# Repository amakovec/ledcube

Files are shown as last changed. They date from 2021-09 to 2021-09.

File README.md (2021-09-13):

# blinky++ - An LED cube with some neat features

## Status

**This project has not yet been tested.  Boards are on their way and bring-up FW writing is in-progress.**

## Features

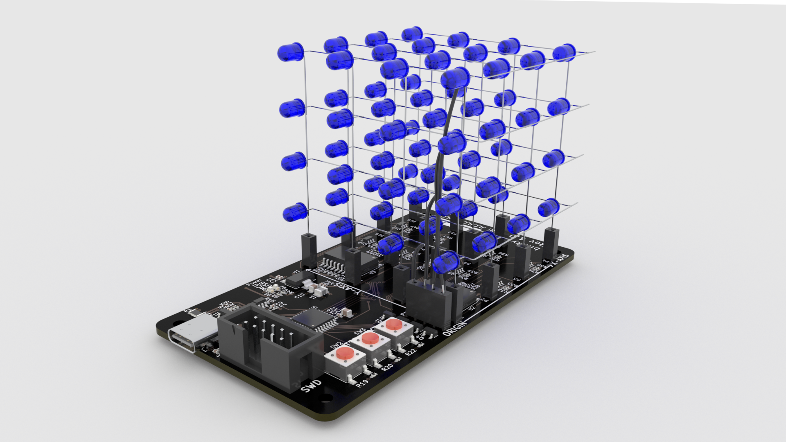
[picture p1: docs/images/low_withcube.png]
blinky++ full rendering


* Multiplex layers at >=120 Hz to create a persistence-of-vision effect
* USB-C for power and communications (except flashing)
    * Set current limit based on CC1 and CC2 voltage (not USB PD)
* Headers to allow for removal of the LED cube
* 30mA per LED
* Buttons to change displayed LED patterns
* Adjustable brightness
    * Limit brightness based on USB current limit determined above

## Hardware

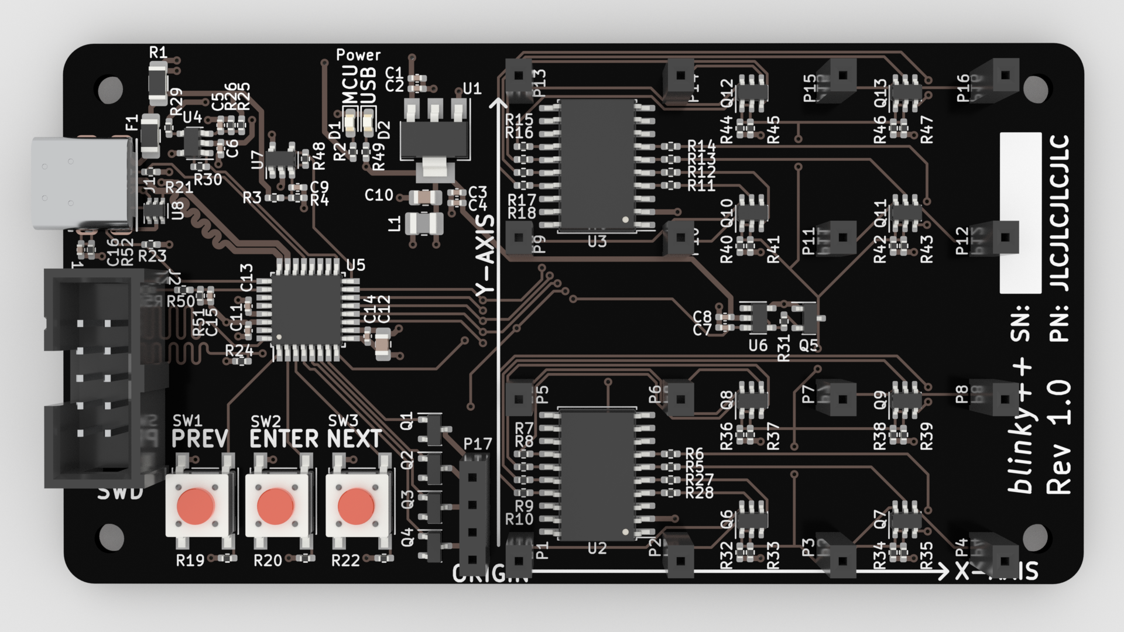
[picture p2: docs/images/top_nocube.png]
blinky++ board-only rendering


* 2-layer board
* Less than 100x100mm (most budget PCB fabs have a significant price jump for dimensions larger than this)
* SAMD21-based

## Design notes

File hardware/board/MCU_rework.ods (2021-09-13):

Pin Number | Pin Name | Net Name | Peripheral Mapping | Remapped from v1.0 Schematic? | Previous Pin Number
1 | PA00 | BUTTON_1 | GPIO | No | --
2 | PA01 | BUTTON_2 | GPIO | No | --
3 | PA02 | BRIGHTNESS_DAC | DAC VOUT | Yes | 8
4 | PA03 | U5V_VSENSE | AIN[1] | Yes | 16
5 | PA04 | U5V_CSENSE | AIN[4] | Yes | 17
6 | PA05 | USB_CC1 | AIN[5] | Yes | 21
7 | PA06 | USB_CC2 | AIN[6] | Yes | 25
8 | PA07 | BUTTON_3 | GPIO | Yes | 3
9 | VDDANA | -- | -- | -- | --
10 | GNDIO | -- | -- | -- | --
11 | PA08 | SHIFT_SER_IN | SERCOM2/PAD[0] (DO) | No | --
12 | PA09 | SHIFT_SRCK | SERCOM2/PAD[1] (SCK) | No | --
13 | PA10 | SHIFT_SRCLR | GPIO | No | --
14 | PA11 | SHIFT_RCLK | GPIO | No | --
15 | PA14 | SHIFT_G | GPIO | No | --
16 | PA15 | LED_N_3 | GPIO | Yes | 4
17 | PA16 | LED_N_2 | GPIO | Yes | 5
18 | PA17 | LED_N_1 | GPIO | Yes | 6
19 | PA18 | LED_N_0 | GPIO | Yes | 7
20 | PA19 | -- | -- | -- | --
21 | PA22 | -- | -- | -- | --
22 | PA23 | -- | -- | -- | --
23 | PA24 | USB_N | USB/DM | No | --
24 | PA25 | USB_P | USB/DP | No | --
25 | PA27 | -- | -- | -- | --
26 | RESET_N | -- | -- | -- | --
27 | PA28 | -- | -- | -- | --
28 | GNDIO | -- | -- | -- | --
29 | VDDCORE | -- | -- | -- | --
30 | VDDIN | -- | -- | -- | --
31 | PA30 | SWCLK | Available | No | --
32 | PA31 | SWDIO | Available | No | --

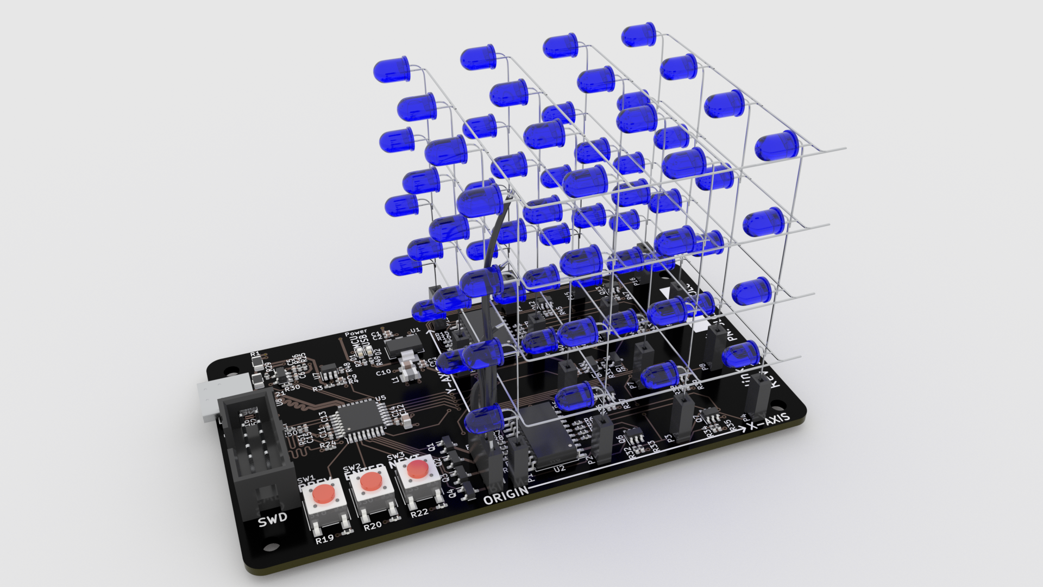
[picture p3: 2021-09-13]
docs/images/high_withcube.png

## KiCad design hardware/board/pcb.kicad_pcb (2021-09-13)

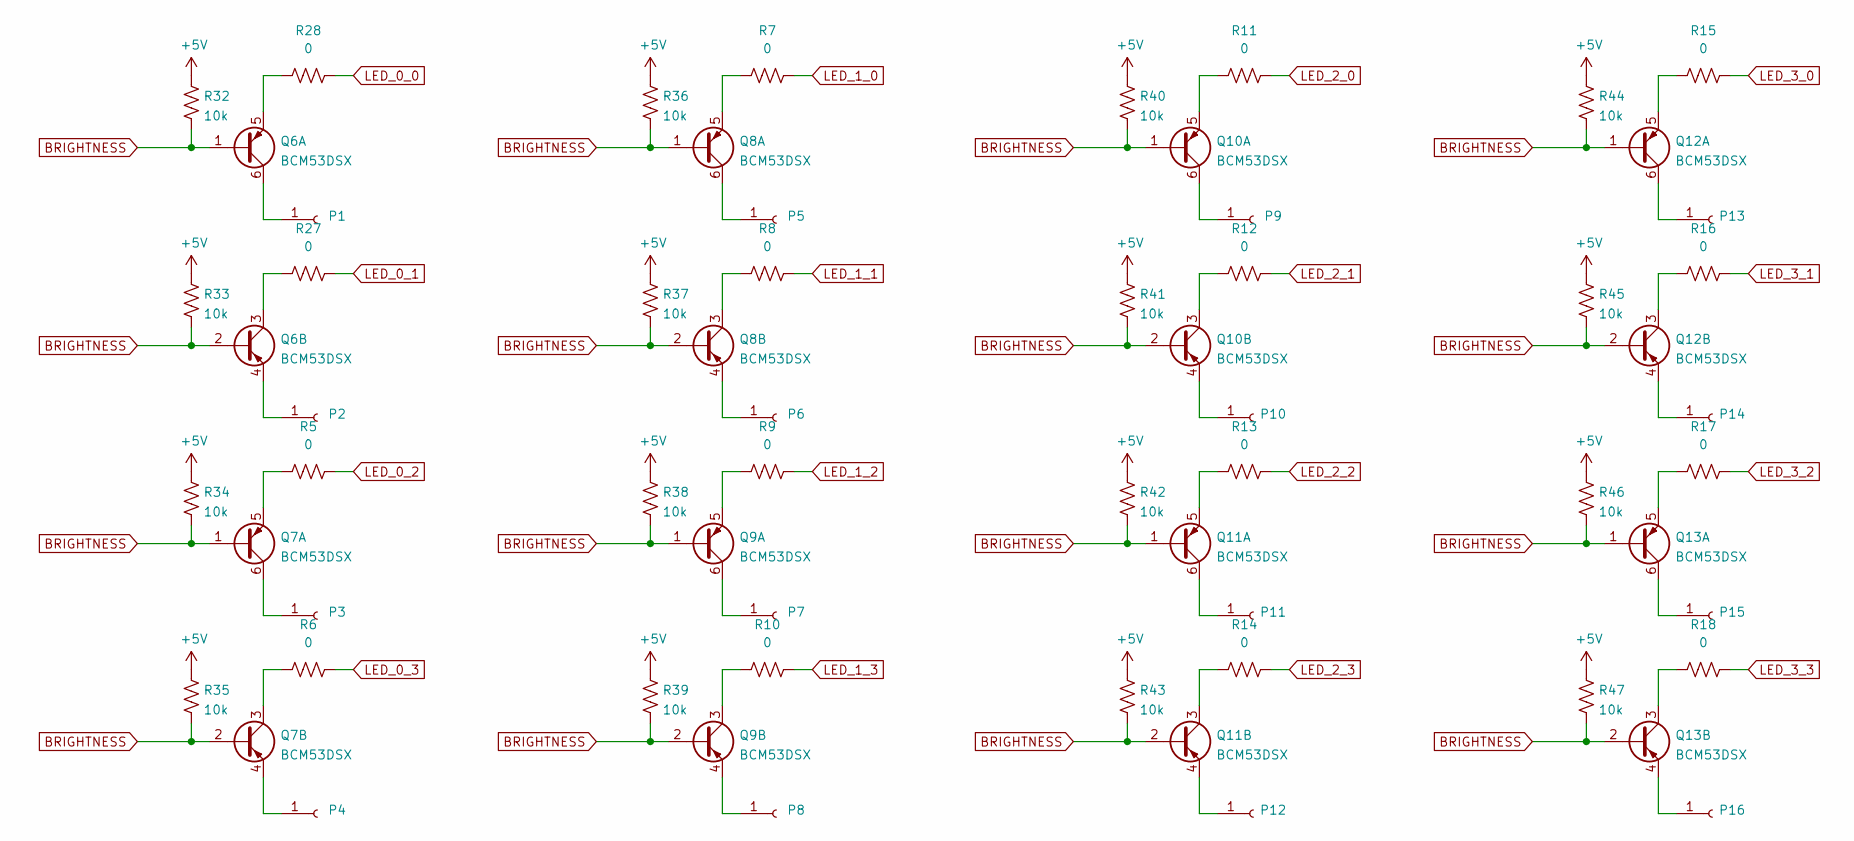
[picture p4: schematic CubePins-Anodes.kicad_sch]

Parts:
P1, P2, P3, P4, P5, P6, P7, P8, P9, P10, P11, P12, P13, P14, P15, P16: SSW-101-01-T-S
Q6, Q7, Q8, Q9, Q10, Q11, Q12, Q13: BCM53DSX; SC-74-6_1.5x2.9mm_P0.95mm
R5, R6, R7, R8, R9, R10, R11, R12, R13, R14, R15, R16, R17, R18, R27, R28: RC0402JR-070RP; R_0402_1005Metric_Pad0.72x0.64mm_HandSolder
R32, R33, R34, R35, R36, R37, R38, R39, R40, R41, R42, R43, R44, R45, R46, R47: RC0402FR-0710KL; R_0402_1005Metric_Pad0.72x0.64mm_HandSolder; Tolerance 1%

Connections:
+5V: R32.1, R33.1, R34.1, R35.1, R36.1, R37.1, R38.1, R39.1, R40.1, R41.1, R42.1, R43.1, R44.1, R45.1, R46.1, R47.1; also elsewhere on the board
BRIGHTNESS: Q6.1 (B2), Q6.2 (B2), Q7.1 (B2), Q7.2 (B2), Q8.1 (B2), Q8.2 (B2), Q9.1 (B2), Q9.2 (B2), Q10.1 (B2), Q10.2 (B2), Q11.1 (B2), Q11.2 (B2), Q12.1 (B2), Q12.2 (B2), Q13.1 (B2), Q13.2 (B2), R32.2, R33.2, R34.2, R35.2, R36.2, R37.2, R38.2, R39.2, R40.2, R41.2, R42.2, R43.2, R44.2, R45.2, R46.2, R47.2; also elsewhere on the board
LED_0_0: R28.1; also elsewhere on the board
LED_0_1: R27.1; also elsewhere on the board
LED_0_2: R5.1; also elsewhere on the board
LED_0_3: R6.1; also elsewhere on the board
LED_1_0: R7.1; also elsewhere on the board
LED_1_1: R8.1; also elsewhere on the board
LED_1_2: R9.1; also elsewhere on the board
LED_1_3: R10.1; also elsewhere on the board
LED_2_0: R11.1; also elsewhere on the board
LED_2_1: R12.1; also elsewhere on the board
LED_2_2: R13.1; also elsewhere on the board
LED_2_3: R14.1; also elsewhere on the board
LED_3_0: R15.1; also elsewhere on the board
LED_3_1: R16.1; also elsewhere on the board
LED_3_2: R17.1; also elsewhere on the board
LED_3_3: R18.1; also elsewhere on the board
unnamed: P1.1, Q6.6 (C2)
unnamed: P2.1, Q6.4 (E2)
unnamed: P3.1, Q7.6 (C2)
unnamed: P4.1, Q7.4 (E2)
unnamed: P5.1, Q8.6 (C2)
unnamed: P6.1, Q8.4 (E2)
unnamed: P7.1, Q9.6 (C2)
unnamed: P8.1, Q9.4 (E2)
unnamed: P9.1, Q10.6 (C2)
unnamed: P10.1, Q10.4 (E2)
unnamed: P11.1, Q11.6 (C2)
unnamed: P12.1, Q11.4 (E2)
unnamed: P13.1, Q12.6 (C2)
unnamed: P14.1, Q12.4 (E2)
unnamed: P15.1, Q13.6 (C2)
unnamed: P16.1, Q13.4 (E2)
unnamed: Q6.3 (C2), R27.2
unnamed: Q6.5 (E2), R28.2
unnamed: Q7.3 (C2), R6.2
unnamed: Q7.5 (E2), R5.2
unnamed: Q8.3 (C2), R8.2
unnamed: Q8.5 (E2), R7.2
unnamed: Q9.3 (C2), R10.2
unnamed: Q9.5 (E2), R9.2
unnamed: Q10.3 (C2), R12.2
unnamed: Q10.5 (E2), R11.2
unnamed: Q11.3 (C2), R14.2
unnamed: Q11.5 (E2), R13.2
unnamed: Q12.3 (C2), R16.2
unnamed: Q12.5 (E2), R15.2
unnamed: Q13.3 (C2), R18.2
unnamed: Q13.5 (E2), R17.2

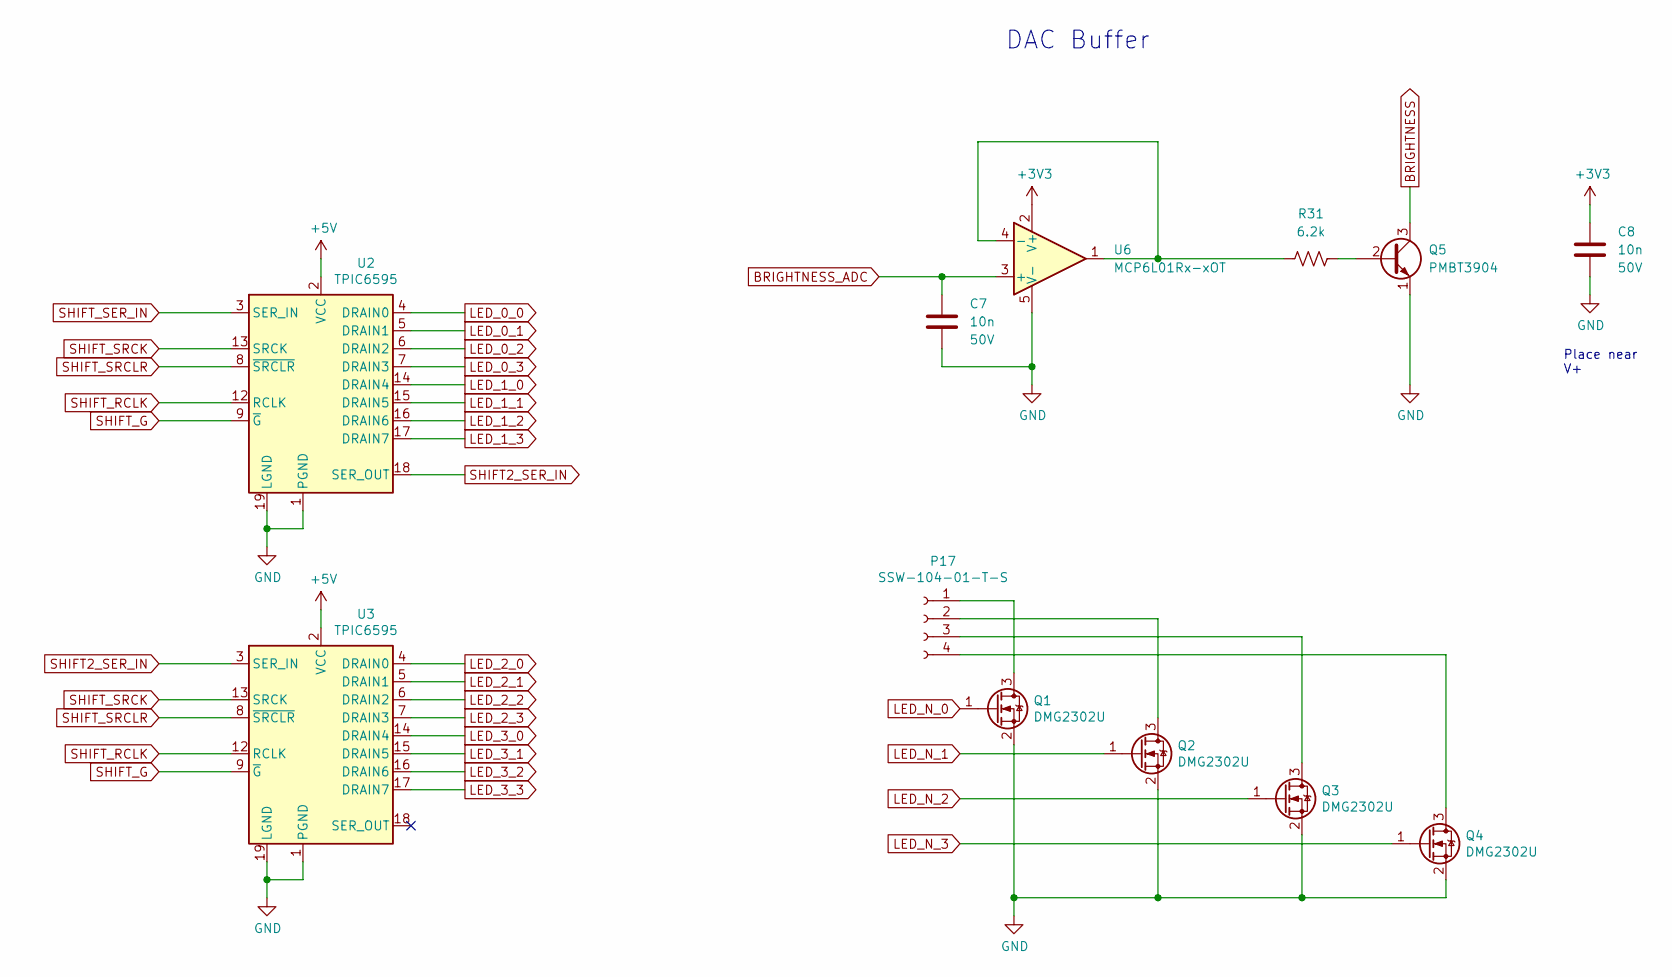
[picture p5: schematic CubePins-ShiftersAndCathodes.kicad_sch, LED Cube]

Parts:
C7, C8: GCM155R71H103KA55D; C_0402_1005Metric_Pad0.74x0.62mm_HandSolder; Voltage 50V; Rating X7R
P17: SSW-104-01-T-S
Q1, Q2, Q3, Q4: DMG2302U; SOT-23
Q5: PMBT3904; SOT-23
R31: RC0402FR-076K2L; R_0402_1005Metric_Pad0.72x0.64mm_HandSolder; Tolerance 1%
U2, U3: TPIC6595; SOIC-20W_7.5x12.8mm_P1.27mm
U6: MCP6L01Rx-xOT; SOT-23-5

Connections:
+3V3: C8.1, U6.2 (V+); also elsewhere on the board
+5V: U2.2 (VCC), U3.2 (VCC); also elsewhere on the board
BRIGHTNESS: Q5.3 (C); also elsewhere on the board
BRIGHTNESS_ADC: C7.1, U6.3 (+); also elsewhere on the board
LED_0_0: U2.4 (DRAIN0); also elsewhere on the board
LED_0_1: U2.5 (DRAIN1); also elsewhere on the board
LED_0_2: U2.6 (DRAIN2); also elsewhere on the board
LED_0_3: U2.7 (DRAIN3); also elsewhere on the board
LED_1_0: U2.14 (DRAIN4); also elsewhere on the board
LED_1_1: U2.15 (DRAIN5); also elsewhere on the board
LED_1_2: U2.16 (DRAIN6); also elsewhere on the board
LED_1_3: U2.17 (DRAIN7); also elsewhere on the board
LED_2_0: U3.4 (DRAIN0); also elsewhere on the board
LED_2_1: U3.5 (DRAIN1); also elsewhere on the board
LED_2_2: U3.6 (DRAIN2); also elsewhere on the board
LED_2_3: U3.7 (DRAIN3); also elsewhere on the board
LED_3_0: U3.14 (DRAIN4); also elsewhere on the board
LED_3_1: U3.15 (DRAIN5); also elsewhere on the board
LED_3_2: U3.16 (DRAIN6); also elsewhere on the board
LED_3_3: U3.17 (DRAIN7); also elsewhere on the board
LED_N_0: Q1.1 (G); also elsewhere on the board
LED_N_1: Q2.1 (G); also elsewhere on the board
LED_N_2: Q3.1 (G); also elsewhere on the board
LED_N_3: Q4.1 (G); also elsewhere on the board
unnamed: P17.1, Q1.3 (D)
unnamed: P17.2, Q2.3 (D)
unnamed: P17.3, Q3.3 (D)
unnamed: P17.4, Q4.3 (D)
unnamed: Q5.2 (B), R31.2
unnamed: R31.1, U6.1, U6.4 (-)
SHIFT2_SER_IN: U2.18 (SER_OUT), U3.3 (SER_IN)
SHIFT_G: U2.9 (~G), U3.9 (~G); also elsewhere on the board
SHIFT_RCLK: U2.12 (RCLK), U3.12 (RCLK); also elsewhere on the board
SHIFT_SER_IN: U2.3 (SER_IN); also elsewhere on the board
SHIFT_SRCK: U2.13 (SRCK), U3.13 (SRCK); also elsewhere on the board
SHIFT_SRCLR: U2.8 (~SRCLR), U3.8 (~SRCLR); also elsewhere on the board

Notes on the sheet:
DAC Buffer
Place near V+

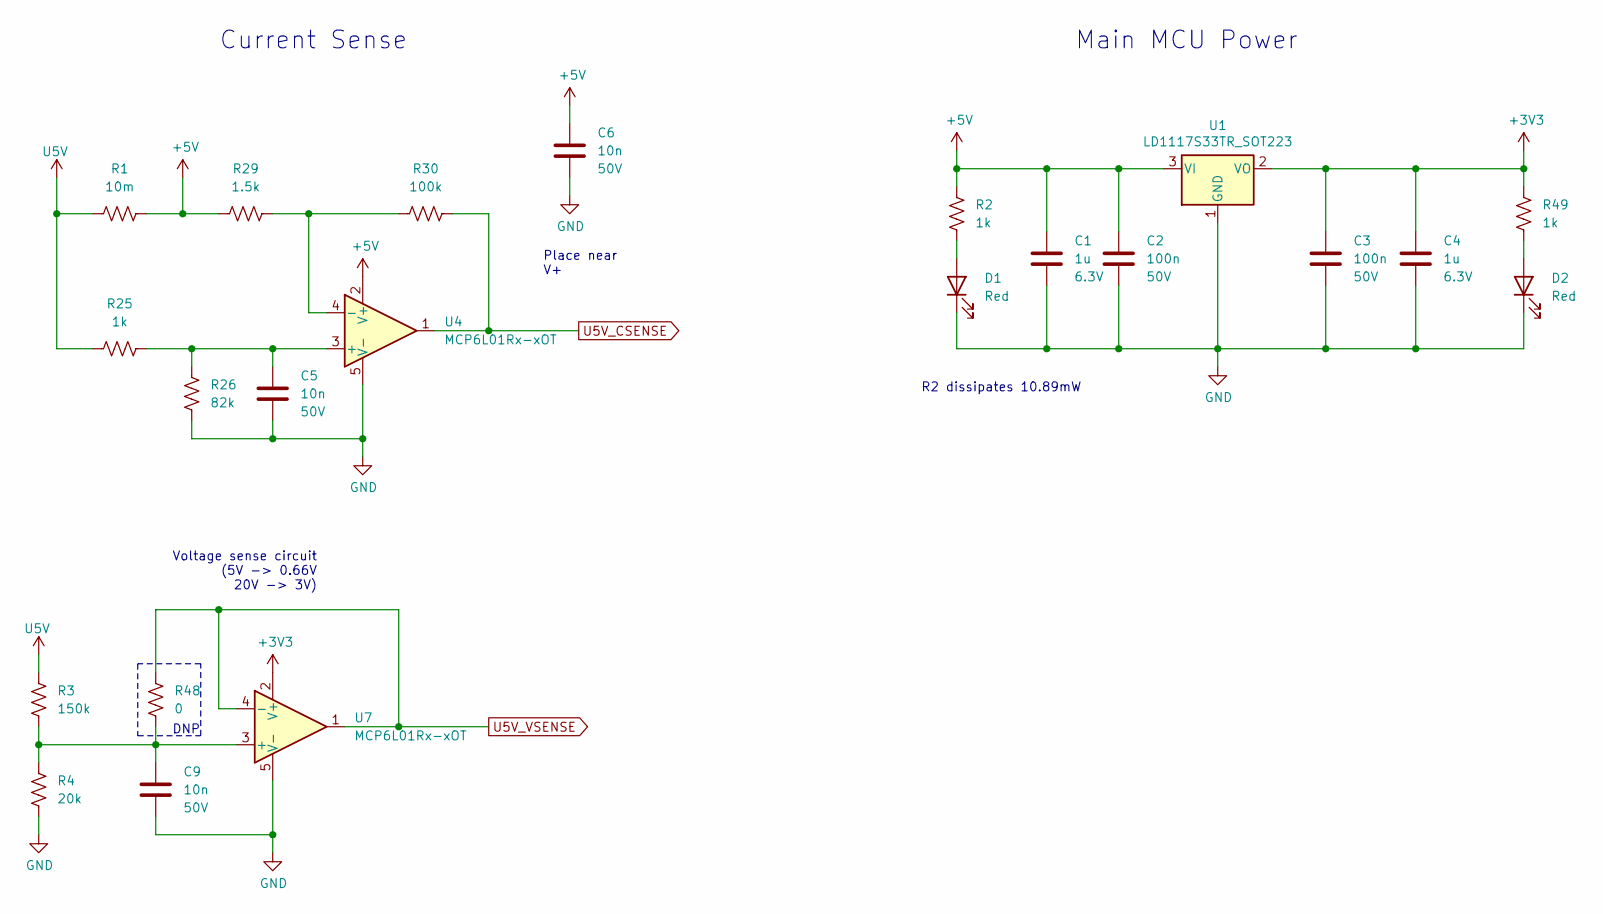
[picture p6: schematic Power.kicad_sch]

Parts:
C1, C4: CC0402KRX5R5BB105; C_0402_1005Metric_Pad0.74x0.62mm_HandSolder; Voltage 6.3V; Rating X5R
C2, C3: GRM155R71H104KE14D; C_0402_1005Metric_Pad0.74x0.62mm_HandSolder; Voltage 50V; Rating X7R
C5, C6, C9: GCM155R71H103KA55D; C_0402_1005Metric_Pad0.74x0.62mm_HandSolder; Voltage 50V; Rating X7R
D1, D2: 150060RS75000; LED_0603_1608Metric_Pad1.05x0.95mm_HandSolder
R1: CFG0612-FX-R010ELF; R_1206_3216Metric_Pad1.30x1.75mm_HandSolder; Tolerance 1%
R2, R49: RC0402JR-071KL; R_0402_1005Metric_Pad0.72x0.64mm_HandSolder
R3: RC0402FR-07150KL; R_0402_1005Metric_Pad0.72x0.64mm_HandSolder; Tolerance 1%
R4: RC0402FR-0720KL; R_0402_1005Metric_Pad0.72x0.64mm_HandSolder; Tolerance 1%
R25: RC0402FR-071KL; R_0402_1005Metric_Pad0.72x0.64mm_HandSolder; Tolerance 1%
R26: RC0402FR-0782KL; R_0402_1005Metric_Pad0.72x0.64mm_HandSolder; Tolerance 1%
R29: RC0402FR-071K5L; R_0402_1005Metric_Pad0.72x0.64mm_HandSolder; Tolerance 1%
R30: RC0402FR-07100KL; R_0402_1005Metric_Pad0.72x0.64mm_HandSolder; Tolerance 1%
R48: RC0402JR-070RP; R_0402_1005Metric_Pad0.72x0.64mm_HandSolder
U1: LD1117S33TR_SOT223; SOT-223-3_TabPin2
U4, U7: MCP6L01Rx-xOT; SOT-23-5

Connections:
+3V3: C3.1, C4.1, R49.1, U1.2 (VO), U7.2 (V+); also elsewhere on the board
+5V: C1.1, C2.1, C6.1, R1.2, R2.1, R29.1, U1.3 (VI), U4.2 (V+); also elsewhere on the board
unnamed: C5.1, R25.2, R26.1, U4.3 (+)
unnamed: C9.1, R3.2, R4.1, R48.1, U7.3 (+)
unnamed: D1.2 (A), R2.2
unnamed: D2.2 (A), R49.2
unnamed: R29.2, R30.1, U4.4 (-)
U5V: R1.1, R3.1, R25.1; also elsewhere on the board
U5V_CSENSE: R30.2, U4.1; also elsewhere on the board
U5V_VSENSE: R48.2, U7.1, U7.4 (-); also elsewhere on the board

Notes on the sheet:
DNP
Current Sense
Voltage sense circuit (5V -> 0.66V 20V -> 3V)
Place near V+
R2 dissipates 10.89mW
Main MCU Power

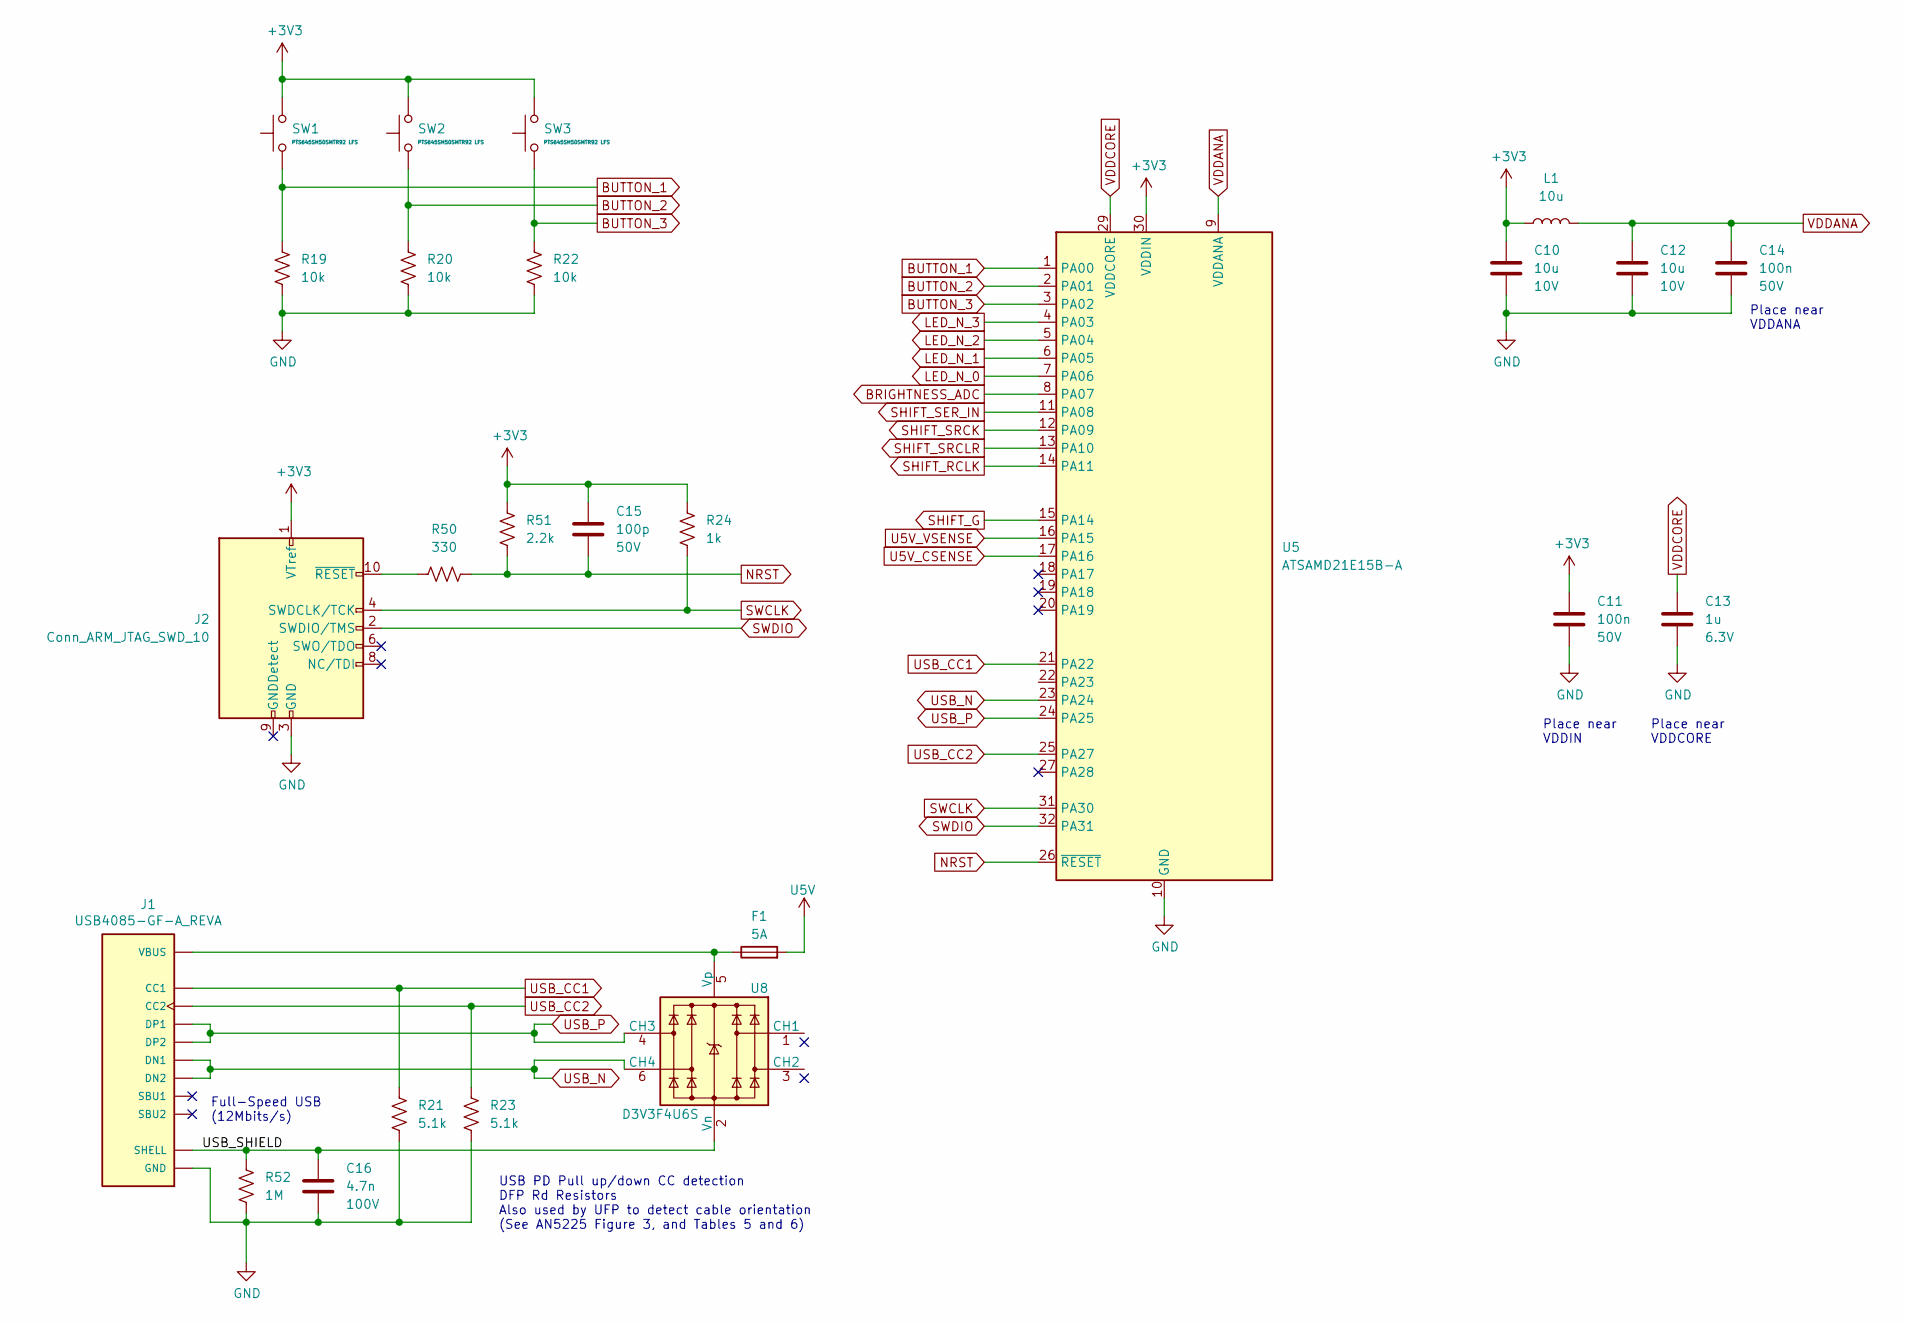
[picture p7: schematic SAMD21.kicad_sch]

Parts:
C10, C12: CL21A106KPCLQNC; C_0805_2012Metric_Pad1.18x1.45mm_HandSolder; Voltage 10V; Rating X5R
C11, C14: GRM155R71H104KE14D; C_0402_1005Metric_Pad0.74x0.62mm_HandSolder; Voltage 50V; Rating X7R
C13: CC0402KRX5R5BB105; C_0402_1005Metric_Pad0.74x0.62mm_HandSolder; Voltage 6.3V; Rating X5R
C15: GRM1555C1H101JA01J; C_0402_1005Metric_Pad0.74x0.62mm_HandSolder; Voltage 50V; Rating C0G
C16: GCM155R72A472KA37D; C_0402_1005Metric_Pad0.74x0.62mm_HandSolder; Voltage 100V; Rating X7R
F1: 0685T5000; Fuse_1206_3216Metric_Pad1.42x1.75mm_HandSolder; Current Rating 5A; Voltage Rating - DC 63V
J1: USB4085-GF-A_REVA; GCT_USB4085-GF-A_REVA; PARTREV A2
J2: Conn_ARM_JTAG_SWD_10; TST-105-01-T-D
L1: CBC2518T100M; L_1008_2520Metric_Pad1.43x2.20mm_HandSolder
R19, R20, R22: RC0402JR-0710KL; R_0402_1005Metric_Pad0.72x0.64mm_HandSolder
R21, R23: RC0402FR-075K1L; R_0402_1005Metric_Pad0.72x0.64mm_HandSolder; Tolerance 1%
R24: RC0402JR-071KL; R_0402_1005Metric_Pad0.72x0.64mm_HandSolder
R50: RC0402FR-07330RL; R_0402_1005Metric_Pad0.72x0.64mm_HandSolder; Tolerance 1%
R51: RK73H1ETTP2201F; R_0402_1005Metric_Pad0.72x0.64mm_HandSolder; Tolerance 1%
R52: CRGCQ0402F1M0; R_0402_1005Metric_Pad0.72x0.64mm_HandSolder; Tolerance 1%
SW1, SW2, SW3: PTS645SH50SMTR92 LFS; SW_Push_1P1T_NO_6x6mm_H9.5mm
U5: ATSAMD21E15B-A; TQFP-32_7x7mm_P0.8mm
U8: D3V3F4U6S; SOT-363_SC-70-6

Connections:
+3V3: C10.1, C11.1, C15.1, J2.1 (VTref), L1.1, R24.1, R51.1, SW1.2, SW2.2, SW3.2, U5.30 (VDDIN); also elsewhere on the board
/SAMD21/USB_SHIELD: C16.1, J1.P1 (SHELL), J1.P2 (SHELL), J1.P3 (SHELL), J1.P4 (SHELL), R52.1, U8.2 (Vn)
BRIGHTNESS_ADC: U5.8 (PA07); also elsewhere on the board
BUTTON_1: R19.2, SW1.1, U5.1 (PA00)
BUTTON_2: R20.2, SW2.1, U5.2 (PA01)
BUTTON_3: R22.2, SW3.1, U5.3 (PA02)
LED_N_0: U5.7 (PA06); also elsewhere on the board
LED_N_1: U5.6 (PA05); also elsewhere on the board
LED_N_2: U5.5 (PA04); also elsewhere on the board
LED_N_3: U5.4 (PA03); also elsewhere on the board
NRST: C15.2, R50.2, R51.2, U5.26 (~RESET)
unnamed: F1.1, J1.A4 (VBUS), J1.A9 (VBUS), J1.B4 (VBUS), J1.B9 (VBUS), U8.5 (Vp)
unnamed: J2.10 (~RESET), R50.1
SHIFT_G: U5.15 (PA14); also elsewhere on the board
SHIFT_RCLK: U5.14 (PA11); also elsewhere on the board
SHIFT_SER_IN: U5.11 (PA08); also elsewhere on the board
SHIFT_SRCK: U5.12 (PA09); also elsewhere on the board
SHIFT_SRCLR: U5.13 (PA10); also elsewhere on the board
SWCLK: J2.4 (SWDCLK/TCK), R24.2, U5.31 (PA30)
SWDIO: J2.2 (SWDIO/TMS), U5.32 (PA31)
U5V: F1.2; also elsewhere on the board
U5V_CSENSE: U5.17 (PA16); also elsewhere on the board
U5V_VSENSE: U5.16 (PA15); also elsewhere on the board
USB_CC1: J1.A5 (CC1), R21.1, U5.21 (PA22)
USB_CC2: J1.B5 (CC2), R23.1, U5.25 (PA27)
USB_N: J1.A7 (DN1), J1.B7 (DN2), U5.23 (PA24), U8.6 (CH4)
USB_P: J1.A6 (DP1), J1.B6 (DP2), U5.24 (PA25), U8.4 (CH3)
VDDANA: C12.1, C14.1, L1.2, U5.9 (VDDANA)
VDDCORE: C13.1, U5.29 (VDDCORE)

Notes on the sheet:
Full-Speed USB (12Mbits/s)
USB PD Pull up/down CC detection DFP Rd Resistors Also used by UFP to detect cable orientation (See AN5225 Figure 3, and Tables 5 and 6)
Place near VDDIN
Place near VDDCORE
Place near VDDANA

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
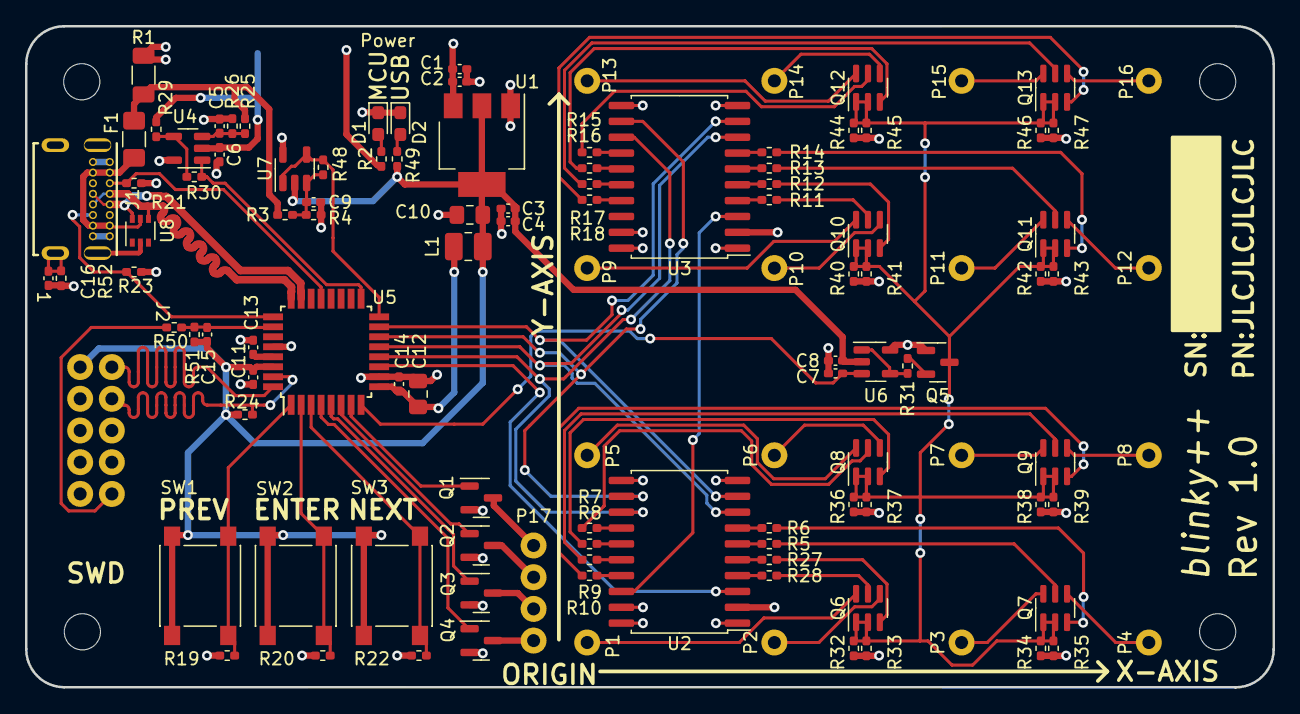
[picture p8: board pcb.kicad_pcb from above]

Board: 2 copper layers, 100.0 x 53.0 mm, 119 parts (0 on the bottom side), 92 nets.

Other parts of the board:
REF1, REF2, REF3, REF4: HEX_STANDOFF_4-40_NYLON_0.5in
